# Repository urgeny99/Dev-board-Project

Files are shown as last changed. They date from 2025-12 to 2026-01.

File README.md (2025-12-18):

Honestly I have no idea what i can do with this DevBoard and I did it because it sounded cool and wanted to get KiCad better to know and what you do with all different functions. I hope that all the time I spent building it is worth it in the end. I have to do some research to learn what i can use the devboard for :)









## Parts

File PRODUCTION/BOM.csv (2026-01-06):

Index | LCSC# | MPN | Manufacturer | Package | Description | RoHS | Quantity | Unit Price($) | Extended Price($) | Product Link
1 | C52923 | CL05A105KA5NQNC | Samsung Electro-Mechanics | 0402 | 1uF ±10% 25V Ceramic Capacitor X5R 0402 | yes | 100 | 0.003 | 0.3 | https://www.lcsc.com/product-detail/C52923.html
2 | C1525 | CL05B104KO5NNNC | Samsung Electro-Mechanics | 0402 | 100nF ±10% 16V Ceramic Capacitor X7R 0402 | yes | 200 | 0.0012 | 0.24 | https://www.lcsc.com/product-detail/C1525.html
3 | C19702 | CL10A106KP8NNNC | Samsung Electro-Mechanics | 0603 | 10uF ±10% 10V Ceramic Capacitor X5R 0603 | yes | 100 | 0.0058 | 0.58 | https://www.lcsc.com/product-detail/C19702.html
4 | C1562 | 0402CG330J500NT | FH | 0402 | 33pF ±5% 50V Ceramic Capacitor C0G 0402 | yes | 100 | 0.0011 | 0.11 | https://www.lcsc.com/product-detail/C1562.html
5 | C965793 | XL-1005UGC | XINGLIGHT | 0402 | Emerald Green 531nm LED Indication - Discrete 3V 0402 | yes | 100 | 0.0076 | 0.76 | https://www.lcsc.com/product-detail/C965793.html
6 | C5149201 | SK6812MINI-E | OPSCO Optoelectronics | SMD | SMD LED Addressable, Specialty RoHS | yes | 10 | 0.0862 | 0.86 | https://www.lcsc.com/product-detail/C5149201.html
7 | C165948 | TYPE-C-31-M-12 | Korean Hroparts Elec | SMD | USB-C (USB TYPE-C) Receptacle Connector 16 Position Surface Mount | yes | 10 | 0.1762 | 1.76 | https://www.lcsc.com/product-detail/C165948.html
8 | C50981 | 2.54-1*20P | BOOMELE(Boom Precision Elec) | Through Hole,P=2.54mm | Pin Header 20 Position 2.54mm Pitch Single Row Through Hole -40℃~+105℃ | yes | 20 | 0.1157 | 2.31 | https://www.lcsc.com/product-detail/C50981.html
9 | C24980 | 1.27-1*3P | BOOMELE(Boom Precision Elec) | Through Hole,P=1.27mm | Pin Header 3 Position 1.27mm Pitch Single Row Through Hole -55℃~+105℃ | yes | 20 | 0.029 | 0.58 | https://www.lcsc.com/product-detail/C24980.html
10 | C25100 | 0402WGF270JTCE | UNI-ROYAL | 0402 | 27Ω ±1% 62.5mW 0402 Thick Film Resistor | yes | 100 | 0.0006 | 0.06 | https://www.lcsc.com/product-detail/C25100.html
11 | C11702 | 0402WGF1001TCE | UNI-ROYAL | 0402 | 1kΩ ±1% 62.5mW 0402 Thick Film Resistor | yes | 100 | 0.0006 | 0.06 | https://www.lcsc.com/product-detail/C11702.html
12 | C25744 | 0402WGF1002TCE | UNI-ROYAL | 0402 | 10kΩ ±1% 62.5mW 0402 Thick Film Resistor | yes | 100 | 0.0006 | 0.06 | https://www.lcsc.com/product-detail/C25744.html
13 | C25900 | 0402WGF4701TCE | UNI-ROYAL | 0402 | 4.7kΩ ±1% 62.5mW 0402 Thick Film Resistor | yes | 100 | 0.0006 | 0.06 | https://www.lcsc.com/product-detail/C25900.html
14 | C25091 | 0402WGF2200TCE | UNI-ROYAL | 0402 | 220Ω ±1% 62.5mW 0402 Thick Film Resistor | yes | 100 | 0.0006 | 0.06 | https://www.lcsc.com/product-detail/C25091.html
15 | C720477 | TS-1088-AR02016 | XUNPU | SMD,4x3mm | Tactile Switch SPST 160gf 2mm SMD (SMT) Tab 4mm x 3mm Surface Mount | yes | 20 | 0.0445 | 0.89 | https://www.lcsc.com/product-detail/C720477.html
16 | C2040 | RP2040 | Raspberry Pi | LQFN-56(7x7) | 133MHz 30 LQFN-56(7x7) Microcontrollers RoHS | yes | 10 | 0.8644 | 8.64 | https://www.lcsc.com/product-detail/C2040.html
17 | C39051 | MCP1700T-3302E/TT | MICROCHIP | SOT-23 | Positive Fixed 3.3V SOT-23 Voltage Regulators - Linear, Low Drop Out (LDO) Regulators RoHS | yes | 10 | 0.3607 | 3.61 | https://www.lcsc.com/product-detail/C39051.html
18 | C2843335 | W25Q16JVUXIQ | Winbond | USON-8-EP(2x3) | 2.7V~3.6V 16Mbit 133MHz SPI USON-8-EP(2x3) Memory (ICs) RoHS | yes | 12 | 0.5048 | 6.06 | https://www.lcsc.com/product-detail/C2843335.html
19 | C9002 | X322512MSB4SI | YXC Crystal Oscillators | SMD3225-4P | Crystal 12MHz ±10ppm 20pF SMD3225-4P | yes | 10 | 0.0685 | 0.69 | https://www.lcsc.com/product-detail/C9002.html
20 | C28927 | TMP112AIDRLR | TI | SOT-563 | Temperature Sensor -40℃~+125℃ SOT-563 | yes | 10 | 0.2273 | 2.27 | https://www.lcsc.com/product-detail/C28927.html
21 | C2906874 | FRC0402F5101TS | FOJAN | 0402 | 5.1kΩ ±1% 62.5mW 0402 Thick Film Resistor | yes | 100 | 0.0005 | 0.05 | https://www.lcsc.com/product-detail/C2906874.html

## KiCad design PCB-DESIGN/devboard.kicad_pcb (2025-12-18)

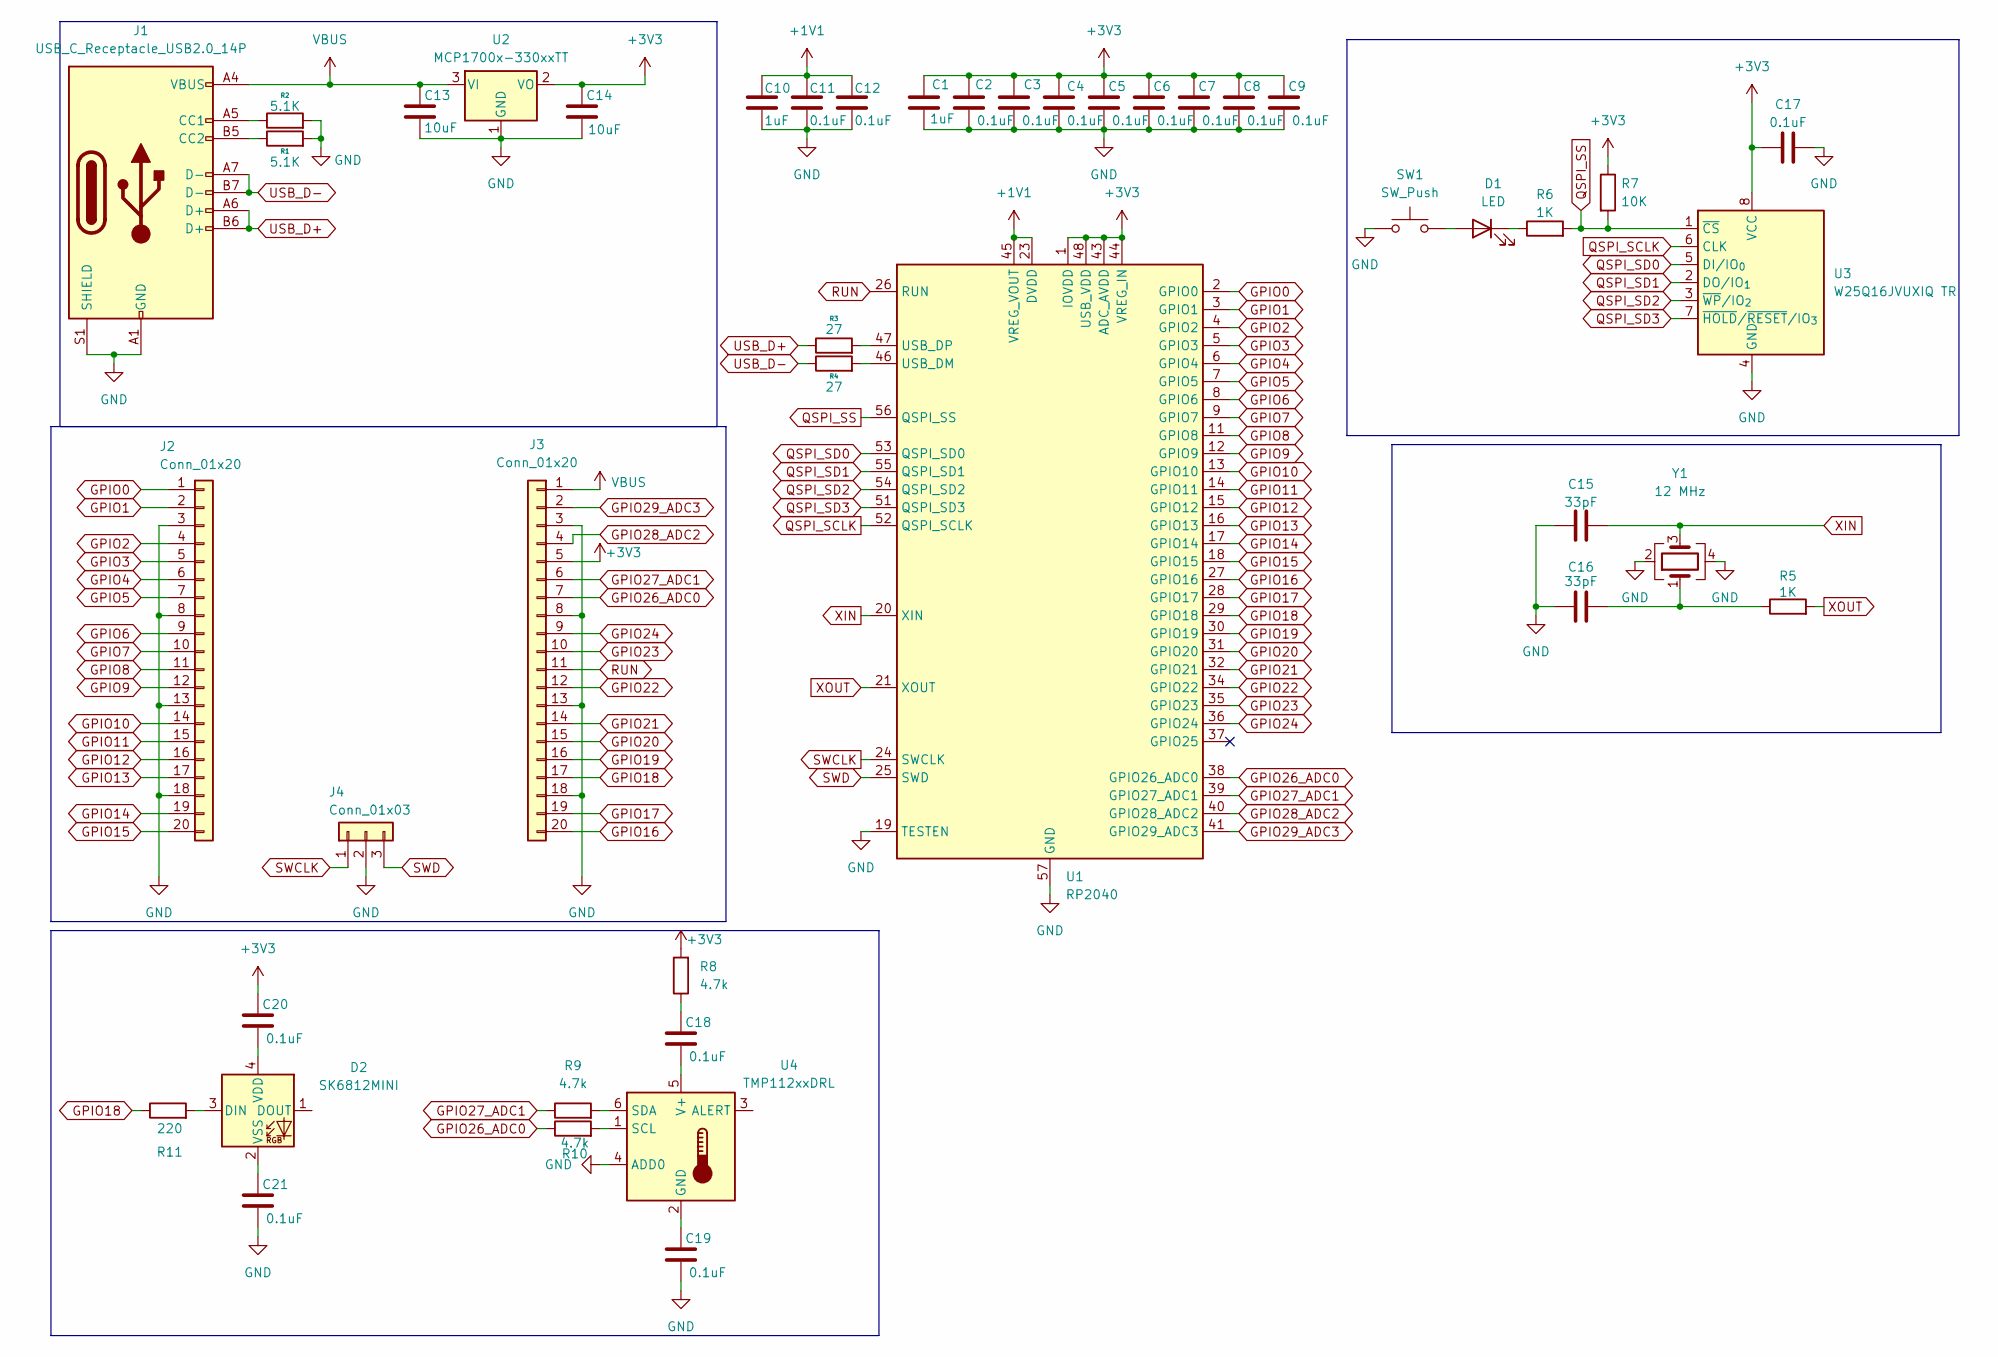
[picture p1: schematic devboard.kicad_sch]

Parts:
C1, C10: 1uF; C_0402_1005Metric
C2, C3, C4, C5, C6, C7, C8, C9, C11, C12, C17, C18, C19, C20, C21: 0.1uF; C_0402_1005Metric
C13, C14: 10uF; C_0603_1608Metric
C15, C16: 33pF; C_0402_1005Metric
D1: LED; LED_0402_1005Metric
D2: SK6812MINI; LED_SK6812MINI_PLCC4_3.5x3.5mm_P1.75mm
J1: USB_C_Receptacle_USB2.0_14P; USB_C_Receptacle_HRO_TYPE-C-31-M-12
J2, J3: Conn_01x20; PinHeader_1x20_P2.54mm_Vertical
J4: Conn_01x03; PinHeader_1x03_P2.54mm_Vertical
R1, R2: 5.1K; R_0402_1005Metric
R3, R4: 27; R_0402_1005Metric
R5, R6: 1K; R_0402_1005Metric
R7: 10K; R_0402_1005Metric
R8, R9, R10: 4.7k; R_0402_1005Metric
R11: 220; R_0402_1005Metric
SW1: SW_Push; SW_Push_SPST_NO_Alps_SKRK
U1: RP2040; QFN-56-1EP_7x7mm_P0.4mm_EP3.2x3.2mm
U2: MCP1700x-330xxTT; SOT-23
U3: W25Q16JVUXIQ TR; Winbond_USON-8-1EP_3x2mm_P0.5mm_EP0.2x1.6mm
U4: TMP112xxDRL; SOT-563
Y1: 12 MHz; Crystal_SMD_3225-4Pin_3.2x2.5mm

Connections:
+1V1: C10.1, C11.1, C12.1, U1.23 (DVDD), U1.45 (VREG_VOUT), U1.50 (DVDD)
+3V3: C1.1, C2.1, C3.1, C4.1, C5.1, C6.1, C7.1, C8.1, C9.1, C14.1, C17.1, C20.1, J3.5, R7.1, R8.2, U1.1 (IOVDD), U1.10 (IOVDD), U1.22 (IOVDD), U1.33 (IOVDD), U1.42 (IOVDD), U1.43 (ADC_AVDD), U1.44 (VREG_IN), U1.48 (USB_VDD), U1.49 (IOVDD), U2.2 (VO), U3.8 (VCC)
GND: C1.2, C2.2, C3.2, C4.2, C5.2, C6.2, C7.2, C8.2, C9.2, C10.2, C11.2, C12.2, C13.2, C14.2, C15.1, C16.1, C17.2, C19.2, C21.2, J1.A1 (GND), J1.A12 (GND), J1.B1 (GND), J1.B12 (GND), J1.S1 (SHIELD), J2.3, J2.8, J2.13, J2.18, J3.3, J3.8, J3.13, J3.18, J4.2, R1.2, R2.2, SW1.1, U1.19 (TESTEN), U1.57 (GND), U2.1 (GND), U3.4 (GND), U4.4 (ADD0), Y1.2, Y1.4
GPIO0: J2.1, U1.2 (GPIO0)
GPIO1: J2.2, U1.3 (GPIO1)
GPIO2: J2.4, U1.4 (GPIO2)
GPIO3: J2.5, U1.5 (GPIO3)
GPIO4: J2.6, U1.6 (GPIO4)
GPIO5: J2.7, U1.7 (GPIO5)
GPIO6: J2.9, U1.8 (GPIO6)
GPIO7: J2.10, U1.9 (GPIO7)
GPIO8: J2.11, U1.11 (GPIO8)
GPIO9: J2.12, U1.12 (GPIO9)
GPIO10: J2.14, U1.13 (GPIO10)
GPIO11: J2.15, U1.14 (GPIO11)
GPIO12: J2.16, U1.15 (GPIO12)
GPIO13: J2.17, U1.16 (GPIO13)
GPIO14: J2.19, U1.17 (GPIO14)
GPIO15: J2.20, U1.18 (GPIO15)
GPIO16: J3.20, U1.27 (GPIO16)
GPIO17: J3.19, U1.28 (GPIO17)
GPIO18: J3.17, R11.1, U1.29 (GPIO18)
GPIO19: J3.16, U1.30 (GPIO19)
GPIO20: J3.15, U1.31 (GPIO20)
GPIO21: J3.14, U1.32 (GPIO21)
GPIO22: J3.12, U1.34 (GPIO22)
GPIO23: J3.10, U1.35 (GPIO23)
GPIO24: J3.9, U1.36 (GPIO24)
GPIO26_ADC0: J3.7, R10.1, U1.38 (GPIO26_ADC0)
GPIO27_ADC1: J3.6, R9.1, U1.39 (GPIO27_ADC1)
GPIO28_ADC2: J3.4, U1.40 (GPIO28_ADC2)
GPIO29_ADC3: J3.2, U1.41 (GPIO29_ADC3)
unnamed: C16.2, R5.1, Y1.1
unnamed: C18.1, R8.1
unnamed: D1.2 (A), SW1.2
unnamed: D1.1 (K), R6.1
unnamed: D2.3 (DIN), R11.2
unnamed: C20.2, D2.4 (VDD)
unnamed: C21.1, D2.2 (VSS)
unnamed: J1.A5 (CC1), R2.1
unnamed: J1.B5 (CC2), R1.1
unnamed: R4.2, U1.46 (USB_DM)
unnamed: R3.2, U1.47 (USB_DP)
unnamed: C19.1, U4.2 (GND)
unnamed: R10.2, U4.1 (SCL)
unnamed: R9.2, U4.6 (SDA)
unnamed: C18.2, U4.5 (V+)
QSPI_SCLK: U1.52 (QSPI_SCLK), U3.6 (CLK)
QSPI_SD0: U1.53 (QSPI_SD0), U3.5 (DI/IO_{0})
QSPI_SD1: U1.55 (QSPI_SD1), U3.2 (DO/IO_{1})
QSPI_SD2: U1.54 (QSPI_SD2), U3.3 (~WP/IO_{2})
QSPI_SD3: U1.51 (QSPI_SD3), U3.7 (~HOLD/~RESET/IO_{3})
QSPI_SS: R6.2, R7.2, U1.56 (QSPI_SS), U3.1 (~CS)
RUN: J3.11, U1.26 (RUN)
SWCLK: J4.1, U1.24 (SWCLK)
SWD: J4.3, U1.25 (SWD)
USB_D+: J1.A6 (D+), J1.B6 (D+), R3.1
USB_D-: J1.A7 (D-), J1.B7 (D-), R4.1
VBUS: C13.1, J1.A4 (VBUS), J1.A9 (VBUS), J1.B4 (VBUS), J1.B9 (VBUS), J3.1, U2.3 (VI)
XIN: C15.2, U1.20 (XIN), Y1.3
XOUT: R5.2, U1.21 (XOUT)

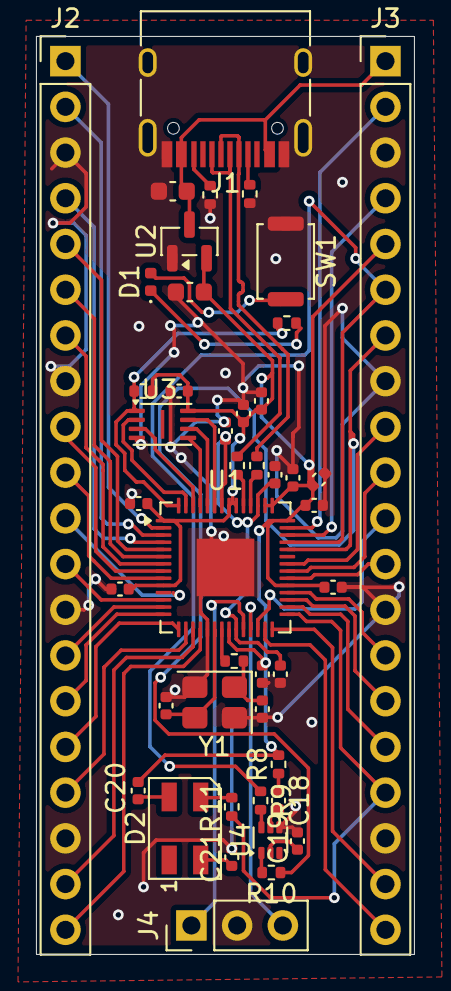
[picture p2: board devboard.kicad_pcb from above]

Board: 2 copper layers, 21.0 x 51.0 mm, 44 parts (0 on the bottom side), 61 nets.

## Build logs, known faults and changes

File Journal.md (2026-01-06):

# This is how i created my DevBoard (full about 30h) :


## Starting my project and doing the first few steps

First I created a schematic for my new project in which i am following the tutorial. 

After I did that I placed down a few capacitors. Then came the USB Connector which took a little bit longer but all of this took only like 3 hours with reading the tutorial and researching about capacitors.

Until now i mostly understood everything i did but i think it will still get more complicated. Next I will be doing the crystal oscillator.



## Added crystal oscillator and flash memory + some research

I added a crystal oscillator to my dev board. Which I found interesting that a little vibrating crystal keeps everything working in order. I than also added a little flash memory for storage. This isnt very much literally 16mb. I then did some research to inform myself about resistors and the RP2040 (and logic gates as a side quest).





## Completed schematic and assigned all footprints

I labeled and connected all of the pins to the "I/O Headers", this took a long time although you can copy paste them. After that I assigned all footprints as shown in the tutorial. I think this was the shortest part in my project.



## Designing the PCB

Wow this took an absolutely long time with all the connecting and placement. Then there was the error fixing that took really long because i had to do so much research and writing in the support channel on slack. The worst thing was moving the parts to better positions because of all the clearance violations.



## After the first reviews they suggested adding something unique so i added a temperature sensor that shows the temp with an rgb led. Main.Py is for the led


## I decided to solder manually so i order the boards from JLCPCB and the parts from LCSC. I ord3er 10 so i can make as many mistakes as i need since i am completely new to this hobby

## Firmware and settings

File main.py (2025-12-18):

import machine
import time
from neopixel import NeoPixel

i2c = machine.I2C(0, scl=machine.Pin(26), sda=machine.Pin(27))
tmp112_address = 0x48

led_pin = machine.Pin(18, machine.Pin.OUT)
num_leds = 1
led_strip = NeoPixel(led_pin, num_leds)

def read_temperature():
    temp_raw = i2c.readfrom_mem(tmp112_address, 0x00, 2)
    temp = (temp_raw[0] << 8 | temp_raw[1]) >> 4
    if temp & 0x800:
        temp -= 4096
    return temp * 0.0625

def set_led_color(temperature):
    if temperature < 15:
        color = (0, 0, 255)
    elif 15 <= temperature <= 25:
        color = (0, 255, 0)
    elif 25 < temperature <= 35:
        color = (255, 255, 0)
    else:
        color = (255, 0, 0)
    led_strip[0] = color
    led_strip.write()

while True:
    temperature = read_temperature()
    print(f"Temperature: {temperature:.2f} °C")
    set_led_color(temperature)
    time.sleep(1)

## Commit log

2025-12-09 Updated ReadMe with my Journal
    Documented the process of creating the DevBoard, including schematic design, component addition, PCB design, and exporting for manufacturing.
2025-12-09 Create PCB_Design
2025-12-10 Create PRODUCTION
    [production_bom.csv]
2025-12-14 Create PCBDESIGN
2025-12-14 Update and rename production_bom.csv to BOM.csv
    [BOM.csv]
